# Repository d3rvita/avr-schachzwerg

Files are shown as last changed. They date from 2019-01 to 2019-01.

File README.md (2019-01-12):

# AVR-Schachzwerg

The AVR-Schachzwerg is a dedicated chess computer based on the 8-bit microcontroller ATmega88. It is very minimalist like its siblings from the late '70s and the early '80s. Four digit 7-segment display, some buttons and a µC, that's it.

AVR-Schachzwerg was originally developed in 2008 by Andre Adrian, he named it "SHAH". In 2009 (or so) Elektor designed and distributed a PCB of this chess computer (aka "AVR-Max Schachcomputer"). But the button layout was just awful and there ware neither a voltage regulator nor connectors for power supply included. So I attempted to make a better PCB layout... 

Schematic is pretty much originally. I only lowered the resistor values for more display brightness and inserted a voltage regulator together with two connectors for power supply. It can be powered either via USB or a ordinary 8-12 VDC power supply (5.5mm / 2.1mm, plus inside).

The program is a adapted version of Micro-Max 4.8. That is a chess engine by H.G. Müller consisting of less than 2000 characters of C code. Playing strength is around 1300 Elo on the www.schachcomputer.info rating list.

EAGLE was used for creating the schematic (schachzwerg.sch) and layout (schachzwerg.brd). gerber-schachzwerg.zip contains all needed gerber files for PCB production. Bill of material is listed in schachzwerg-bom.txt. All components are designed as THT for easy assembly. It is highly recommended using a socket for the µC. __In order to prevent side effects or even damage don't feed both power supply connectors simultaneously!__

## Schematic

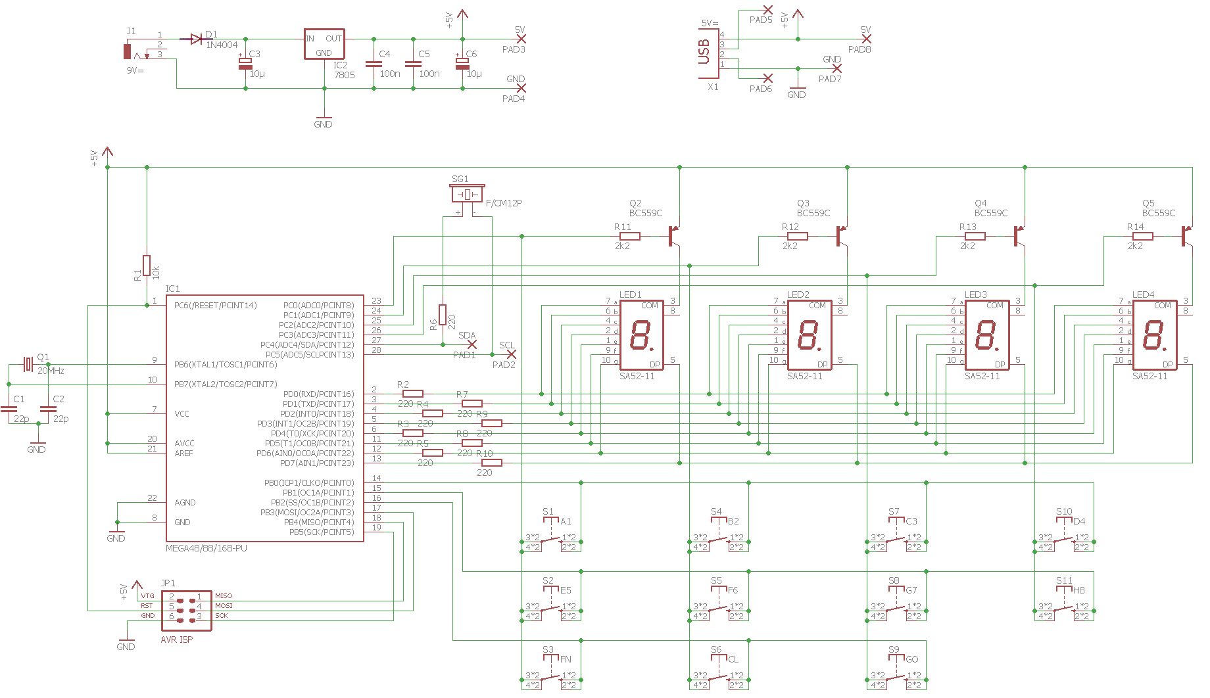
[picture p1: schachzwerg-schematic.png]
Schematic


## PCB

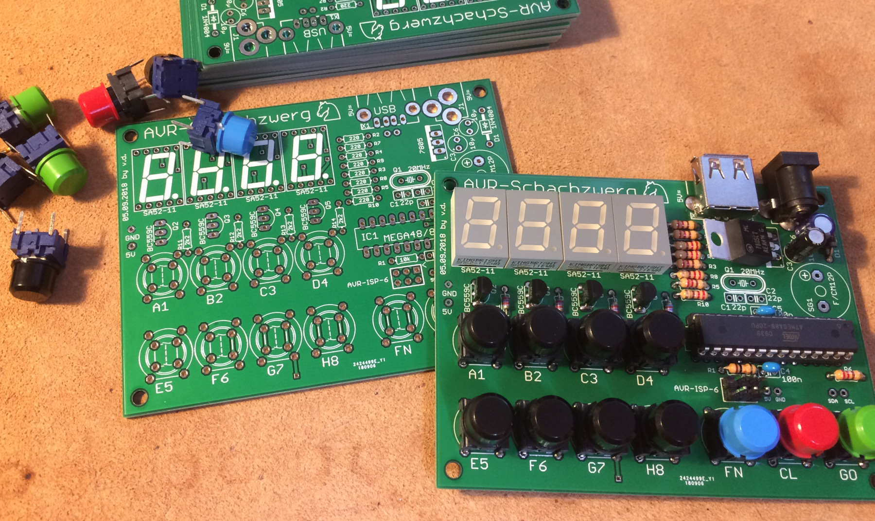
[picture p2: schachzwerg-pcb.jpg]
PCB


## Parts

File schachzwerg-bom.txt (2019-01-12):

Part       Value               Device             Package        Description                                                 
C1*        22p                 C-EU025-025X050    C025-025X050   CAPACITOR, European symbol                                  
C2*        22p                 C-EU025-025X050    C025-025X050   CAPACITOR, European symbol                                  
C3         10µ                 CPOL-EUE2.5-5      E2,5-5         POLARIZED CAPACITOR, European symbol                        
C4         100n                C-EU025-025X050    C025-025X050   CAPACITOR, European symbol                                  
C5         100n                C-EU025-025X050    C025-025X050   CAPACITOR, European symbol                                  
C6         10µ                 CPOL-EUE2.5-5      E2,5-5         POLARIZED CAPACITOR, European symbol                        
D1         1N4004              1N4004             DO41-10        DIODE                                                       
IC1**      MEGA48/88/168-PU    MEGA48/88/168-PU   DIL28-3        MICROCONTROLLER                                             
IC2        7805                78XXS              TO220          VOLTAGE REGULATOR                                           
J1         9V=                 DCJ0303            DCJ0303        DC POWER JACK (5.5mm / 2.1mm)                               
JP1        AVR-ISP-6           AVR-ISP-6          AVR-ISP-6      AVR ISP-6 Serial Programming Header                         
LED1       SA52-11             7-SEG_SA52-11      SA52-11        Kingbright 14.2mm (0.56 INCH) SINGLE DIGIT NUMERIC DUISPLAY 
LED2       SA52-11             7-SEG_SA52-11      SA52-11        Kingbright 14.2mm (0.56 INCH) SINGLE DIGIT NUMERIC DUISPLAY 
LED3       SA52-11             7-SEG_SA52-11      SA52-11        Kingbright 14.2mm (0.56 INCH) SINGLE DIGIT NUMERIC DUISPLAY 
LED4       SA52-11             7-SEG_SA52-11      SA52-11        Kingbright 14.2mm (0.56 INCH) SINGLE DIGIT NUMERIC DUISPLAY 
Q1*        20MHz               CRYSTAL            HC49/S         CRYSTAL                                                     
Q2         BC559C              BC559C             TO92-EBC       PNP Transistor                                             
Q3         BC559C              BC559C             TO92-EBC       PNP Transistor                                             
Q4         BC559C              BC559C             TO92-EBC       PNP Transistor                                             
Q5         BC559C              BC559C             TO92-EBC       PNP Transistor                                             
R1         10k                 R-EU_0204/7        0204/7         RESISTOR, European symbol                                   
R2         220                 R-EU_0204/7        0204/7         RESISTOR, European symbol                                   
R3         220                 R-EU_0204/7        0204/7         RESISTOR, European symbol                                   
R4         220                 R-EU_0204/7        0204/7         RESISTOR, European symbol                                   
R5         220                 R-EU_0204/7        0204/7         RESISTOR, European symbol                                   
R6***      220                 R-EU_0204/7        0204/7         RESISTOR, European symbol                                   
R7         220                 R-EU_0204/7        0204/7         RESISTOR, European symbol                                   
R8         220                 R-EU_0204/7        0204/7         RESISTOR, European symbol                                   
R9         220                 R-EU_0204/7        0204/7         RESISTOR, European symbol                                   
R10        220                 R-EU_0204/7        0204/7         RESISTOR, European symbol                                   
R11        2k2                 R-EU_0204/7        0204/7         RESISTOR, European symbol                                   
R12        2k2                 R-EU_0204/7        0204/7         RESISTOR, European symbol                                   
R13        2k2                 R-EU_0204/7        0204/7         RESISTOR, European symbol                                   
R14        2k2                 R-EU_0204/7        0204/7         RESISTOR, European symbol                                   
S1         A1                  3FTH9 / DT6        3FTH9 / DT6    SWITCH, MULTIMEC 3FTH9 (10.16x7.62mm) OR ITT DT6 (5x5mm)    
S2         E5                  3FTH9 / DT6        3FTH9 / DT6    SWITCH, MULTIMEC 3FTH9 (10.16x7.62mm) OR ITT DT6 (5x5mm)    
S3         FN                  3FTH9 / DT6        3FTH9 / DT6    SWITCH, MULTIMEC 3FTH9 (10.16x7.62mm) OR ITT DT6 (5x5mm)    
S4         B2                  3FTH9 / DT6        3FTH9 / DT6    SWITCH, MULTIMEC 3FTH9 (10.16x7.62mm) OR ITT DT6 (5x5mm)    
S5         F6                  3FTH9 / DT6        3FTH9 / DT6    SWITCH, MULTIMEC 3FTH9 (10.16x7.62mm) OR ITT DT6 (5x5mm)    
S6         CL                  3FTH9 / DT6        3FTH9 / DT6    SWITCH, MULTIMEC 3FTH9 (10.16x7.62mm) OR ITT DT6 (5x5mm)    
S7         C3                  3FTH9 / DT6        3FTH9 / DT6    SWITCH, MULTIMEC 3FTH9 (10.16x7.62mm) OR ITT DT6 (5x5mm)    
S8         G7                  3FTH9 / DT6        3FTH9 / DT6    SWITCH, MULTIMEC 3FTH9 (10.16x7.62mm) OR ITT DT6 (5x5mm)    
S9         GO                  3FTH9 / DT6        3FTH9 / DT6    SWITCH, MULTIMEC 3FTH9 (10.16x7.62mm) OR ITT DT6 (5x5mm)    
S10        D4                  3FTH9 / DT6        3FTH9 / DT6    SWITCH, MULTIMEC 3FTH9 (10.16x7.62mm) OR ITT DT6 (5x5mm)    
S11        H8                  3FTH9 / DT6        3FTH9 / DT6    SWITCH, MULTIMEC 3FTH9 (10.16x7.62mm) OR ITT DT6 (5x5mm)    
SG1***     F/CM12P             F/CM12P            F/CM12P        BUZZER                                                      
X1         5V=                 PN87520            PN87520        USB-A connector                                             

*optional for higher speed
**socket is recommended
***not used yet

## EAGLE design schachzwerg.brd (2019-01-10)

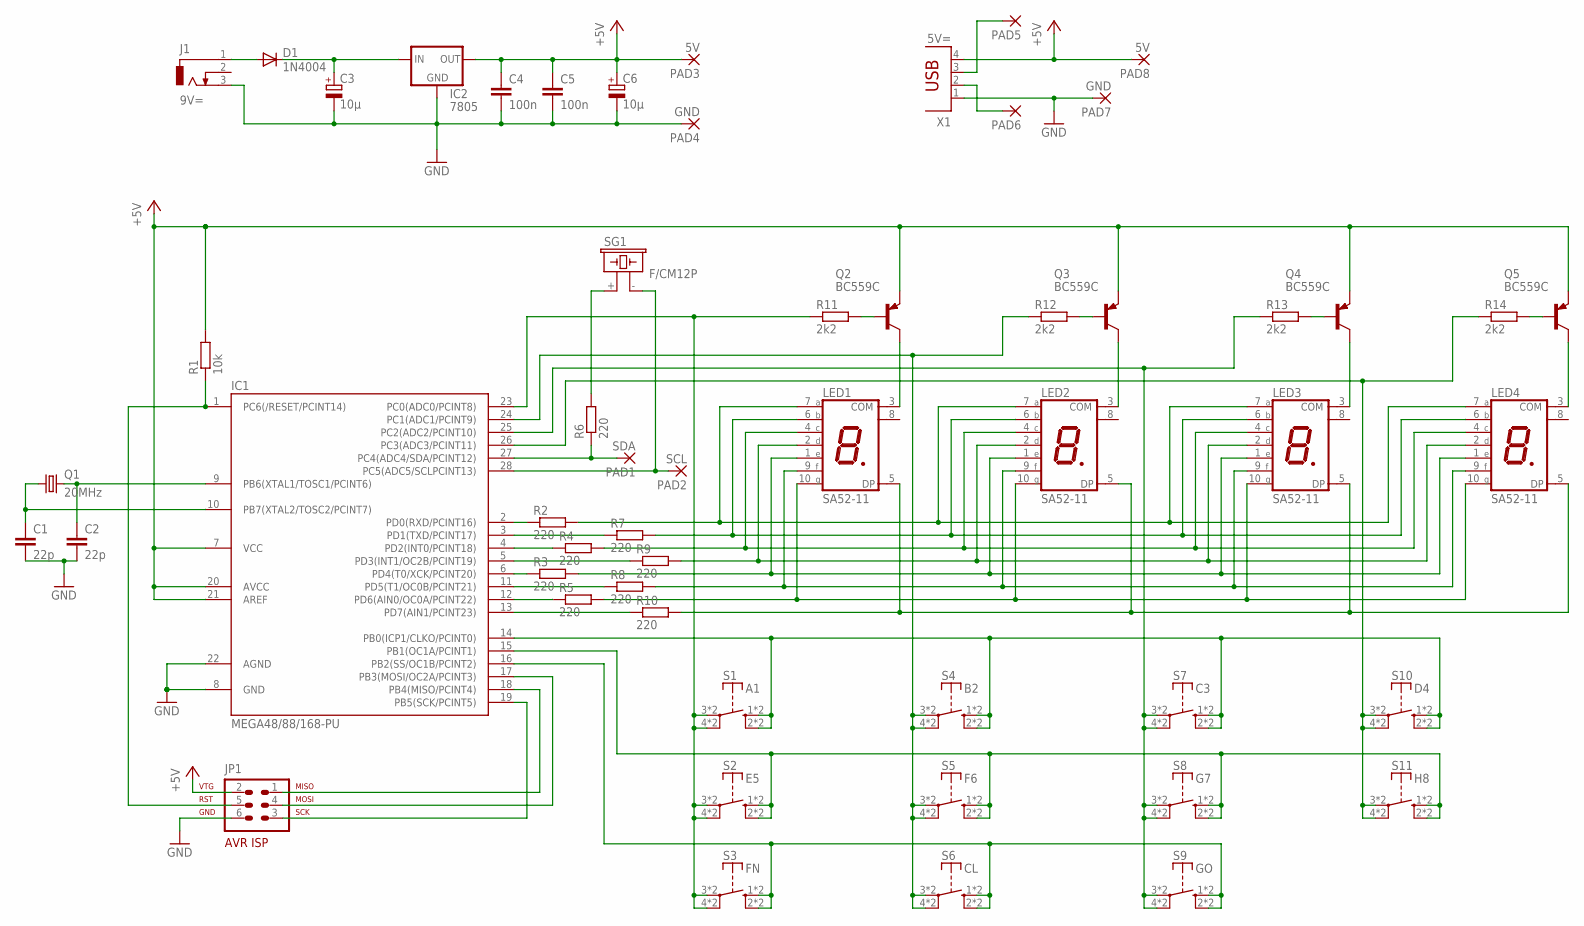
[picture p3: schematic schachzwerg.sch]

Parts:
C1, C2: 22p; C025-025X050
C3, C6: 10µ; E2,5-5
C4, C5: 100n; C025-025X050
D1: 1N4004; DO41-10
IC1: MEGA48/88/168-PU; DIL28-3
IC2: 7805; 78XXS
J1: 9V=; DCJ0303
JP1: AVR-ISP-6
LED1, LED2, LED3, LED4: SA52-11
PAD1: SDA; 1,6/0,8
PAD2: SCL; 1,6/0,8
PAD3, PAD8: 5V; 1,6/0,8
PAD4, PAD7: GND; 1,6/0,8
PAD5, PAD6: 1,6/0,8
Q1: 20MHz; HC49/S
Q2, Q3, Q4, Q5: BC559C; TO92-EBC
R1: 10k; 0204/7
R2, R3, R4, R5, R6, R7, R8, R9, R10: 220; 0204/7
R11, R12, R13, R14: 2k2; 0204/7
S1: A1; DT6
S2: E5; DT6
S3: FN; DT6
S4: B2; DT6
S5: F6; DT6
S6: CL; DT6
S7: C3; DT6
S8: G7; DT6
S9: GO; DT6
S10: D4; DT6
S11: H8; DT6
SG1: F/CM12P
X1: 5V=; PN87520

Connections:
+5V: C4.1, C5.1, C6.+, IC1.7 (VCC), IC1.20 (AVCC), IC1.21 (AREF), IC2.OUT, JP1.2, PAD3.1, PAD8.1, Q2.E, Q3.E, Q4.E, Q5.E, R1.2, X1.4
GND: C1.2, C2.2, C3.-, C4.2, C5.2, C6.-, IC1.8 (GND), IC1.22 (AGND), IC2.GND, J1.3, JP1.6, PAD4.1, PAD7.1, X1.1
unnamed: IC1.2 (PD0(RXD/PCINT16)), R2.1
unnamed: IC1.3 (PD1(TXD/PCINT17)), R7.1
unnamed: IC1.4 (PD2(INT0/PCINT18)), R4.1
unnamed: IC1.5 (PD3(INT1/OC2B/PCINT19)), R9.1
unnamed: IC1.6 (PD4(T0/XCK/PCINT20)), R3.1
unnamed: IC1.11 (PD5(T1/OC0B/PCINT21)), R8.1
unnamed: IC1.12 (PD6(AIN0/OC0A/PCINT22)), R5.1
unnamed: IC1.13 (PD7(AIN1/PCINT23)), R10.1
unnamed: LED1.7 (A), LED2.7 (A), LED3.7 (A), LED4.7 (A), R2.2
unnamed: LED1.6 (B), LED2.6 (B), LED3.6 (B), LED4.6 (B), R7.2
unnamed: LED1.4 (C), LED2.4 (C), LED3.4 (C), LED4.4 (C), R4.2
unnamed: LED1.2 (D), LED2.2 (D), LED3.2 (D), LED4.2 (D), R9.2
unnamed: LED1.1 (E), LED2.1 (E), LED3.1 (E), LED4.1 (E), R3.2
unnamed: LED1.9 (F), LED2.9 (F), LED3.9 (F), LED4.9 (F), R8.2
unnamed: LED1.10 (G), LED2.10 (G), LED3.10 (G), LED4.10 (G), R5.2
unnamed: LED1.5 (DP), LED2.5 (DP), LED3.5 (DP), LED4.5 (DP), R10.2
unnamed: LED1.3 (COM), Q2.C
unnamed: LED2.3 (COM), Q3.C
unnamed: LED3.3 (COM), Q4.C
unnamed: LED4.3 (COM), Q5.C
unnamed: Q2.B, R11.2
unnamed: Q3.B, R12.2
unnamed: Q4.B, R13.2
unnamed: Q5.B, R14.2
unnamed: C2.1, IC1.9 (PB6(XTAL1/TOSC1/PCINT6)), Q1.2
unnamed: PAD6.1, X1.2
unnamed: R6.2, SG1.+ (1)
unnamed: IC1.28 (PC5(ADC5/SCLPCINT13)), PAD2.1, SG1.- (2)
unnamed: D1.A, J1.1
unnamed: IC1.1 (PC6(/RESET/PCINT14)), JP1.5, R1.1
unnamed: IC1.19 (PB5(SCK/PCINT5)), JP1.3
unnamed: IC1.17 (PB3(MOSI/OC2A/PCINT3)), JP1.4
unnamed: IC1.18 (PB4(MISO/PCINT4)), JP1.1
unnamed: IC1.23 (PC0(ADC0/PCINT8)), R11.1, S1.3, S1.4, S1.7, S1.8, S2.3, S2.4, S2.7, S2.8, S3.3, S3.4, S3.7, S3.8
unnamed: IC1.24 (PC1(ADC1/PCINT9)), R12.1, S4.3, S4.4, S4.7, S4.8, S5.3, S5.4, S5.7, S5.8, S6.3, S6.4, S6.7, S6.8
unnamed: IC1.25 (PC2(ADC2/PCINT10)), R13.1, S7.3, S7.4, S7.7, S7.8, S8.3, S8.4, S8.7, S8.8, S9.3, S9.4, S9.7, S9.8
unnamed: IC1.26 (PC3(ADC3/PCINT11)), R14.1, S10.3, S10.4, S10.7, S10.8, S11.3, S11.4, S11.7, S11.8
unnamed: IC1.14 (PB0(ICP1/CLKO/PCINT0)), S1.1 (S), S1.2 (S), S1.5 (S), S1.6 (S), S4.1 (S), S4.2 (S), S4.5 (S), S4.6 (S), S7.1 (S), S7.2 (S), S7.5 (S), S7.6 (S), S10.1 (S), S10.2 (S), S10.5 (S), S10.6 (S)
unnamed: PAD5.1, X1.3
unnamed: IC1.15 (PB1(OC1A/PCINT1)), S2.1 (S), S2.2 (S), S2.5 (S), S2.6 (S), S5.1 (S), S5.2 (S), S5.5 (S), S5.6 (S), S8.1 (S), S8.2 (S), S8.5 (S), S8.6 (S), S11.1 (S), S11.2 (S), S11.5 (S), S11.6 (S)
unnamed: IC1.16 (PB2(SS/OC1B/PCINT2)), S3.1 (S), S3.2 (S), S3.5 (S), S3.6 (S), S6.1 (S), S6.2 (S), S6.5 (S), S6.6 (S), S9.1 (S), S9.2 (S), S9.5 (S), S9.6 (S)
unnamed: C3.+, D1.C, IC2.IN
unnamed: C1.1, IC1.10 (PB7(XTAL2/TOSC2/PCINT7)), Q1.1
unnamed: IC1.27 (PC4(ADC4/SDA/PCINT12)), PAD1.1, R6.1

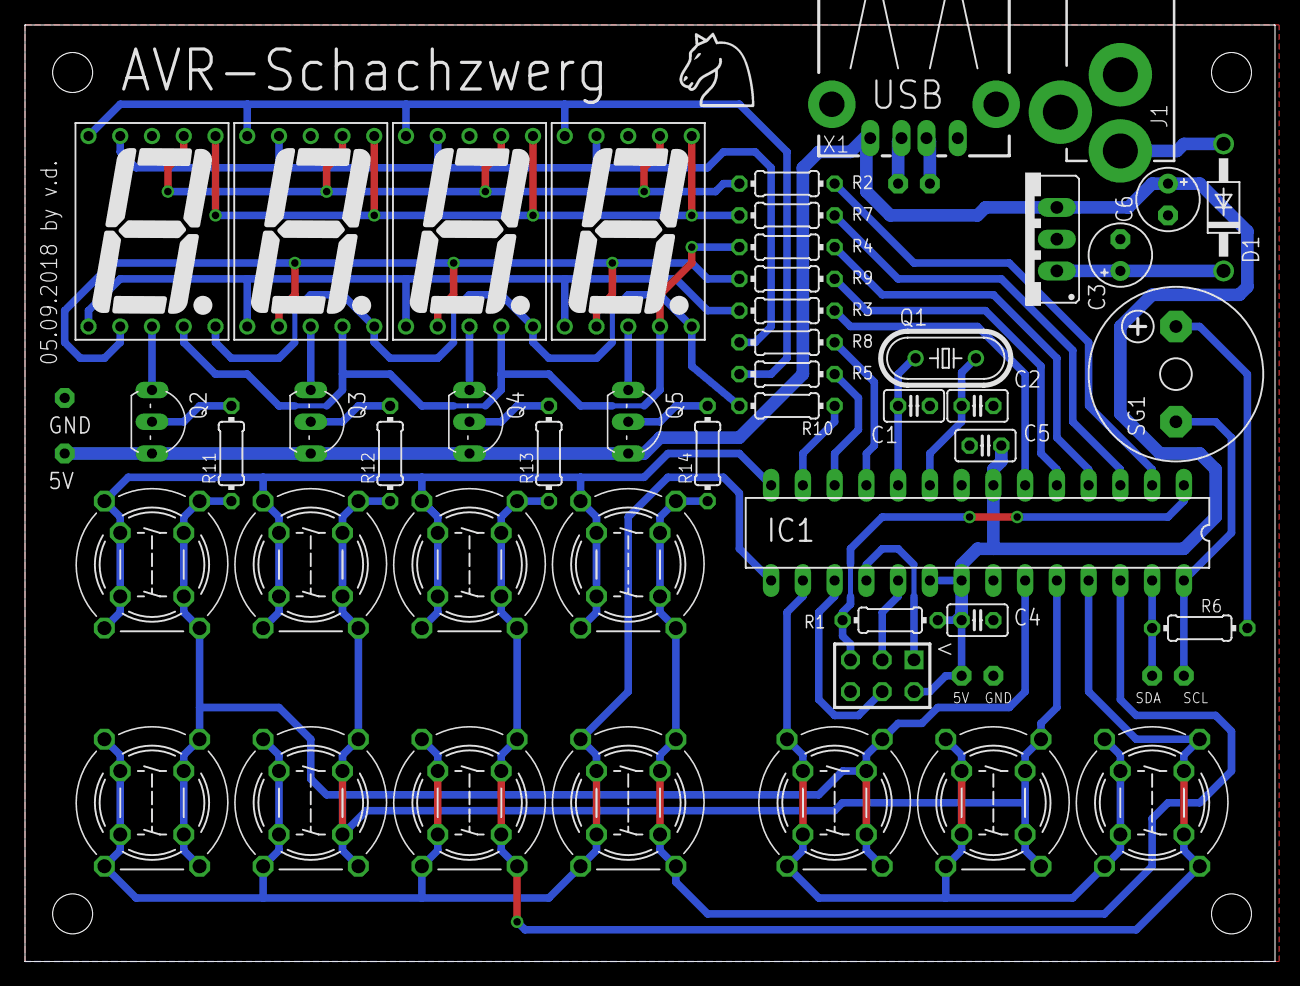
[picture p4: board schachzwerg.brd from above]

Board: 2 copper layers, 100.0 x 74.9 mm, 55 parts (0 on the bottom side), 46 nets.
